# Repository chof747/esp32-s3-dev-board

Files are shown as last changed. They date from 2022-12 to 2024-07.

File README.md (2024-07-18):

# ESP32-S3 Development Board
Minimal development board for an ESP32-S3 MCU.

It contains the following elements:

- ESP32 MCU with all available pins broken out
- Programming header with DTR/RTS mechanism
- Power LED
- Fuse to prevent the worse
- Jumper to disconnect 3v3 from the programmer to be able to test e.g. battery mode while still debugging

## Used Parts:

## Revision History:

- **v1.0**: Initial version (filed for fabrication: 19.11.2022, first successfull assembly: 29.11.2022)
- **v1.1**: Changed serial programmer to UMH3 chip and added boot button

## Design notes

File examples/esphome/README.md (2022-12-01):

# ESP Home example firmware

## Setup instructions

Up until (approx) 21st of December 2022 the ESP32-S3 Devkit Board C1 is not supported by the standard ESPHome version so please do the following:

1. Setup a venv in the esphome samples directory 
2. Activate the environment 
3. Install the development version of esphome

```bash
python3 -m venv esphome-dev
source esphome-dev/bin/activate
esphome-dev/bin/python3 -m pip install --upgrade pip
pip3 install https://github.com/esphome/esphome/archive/dev.zip
```

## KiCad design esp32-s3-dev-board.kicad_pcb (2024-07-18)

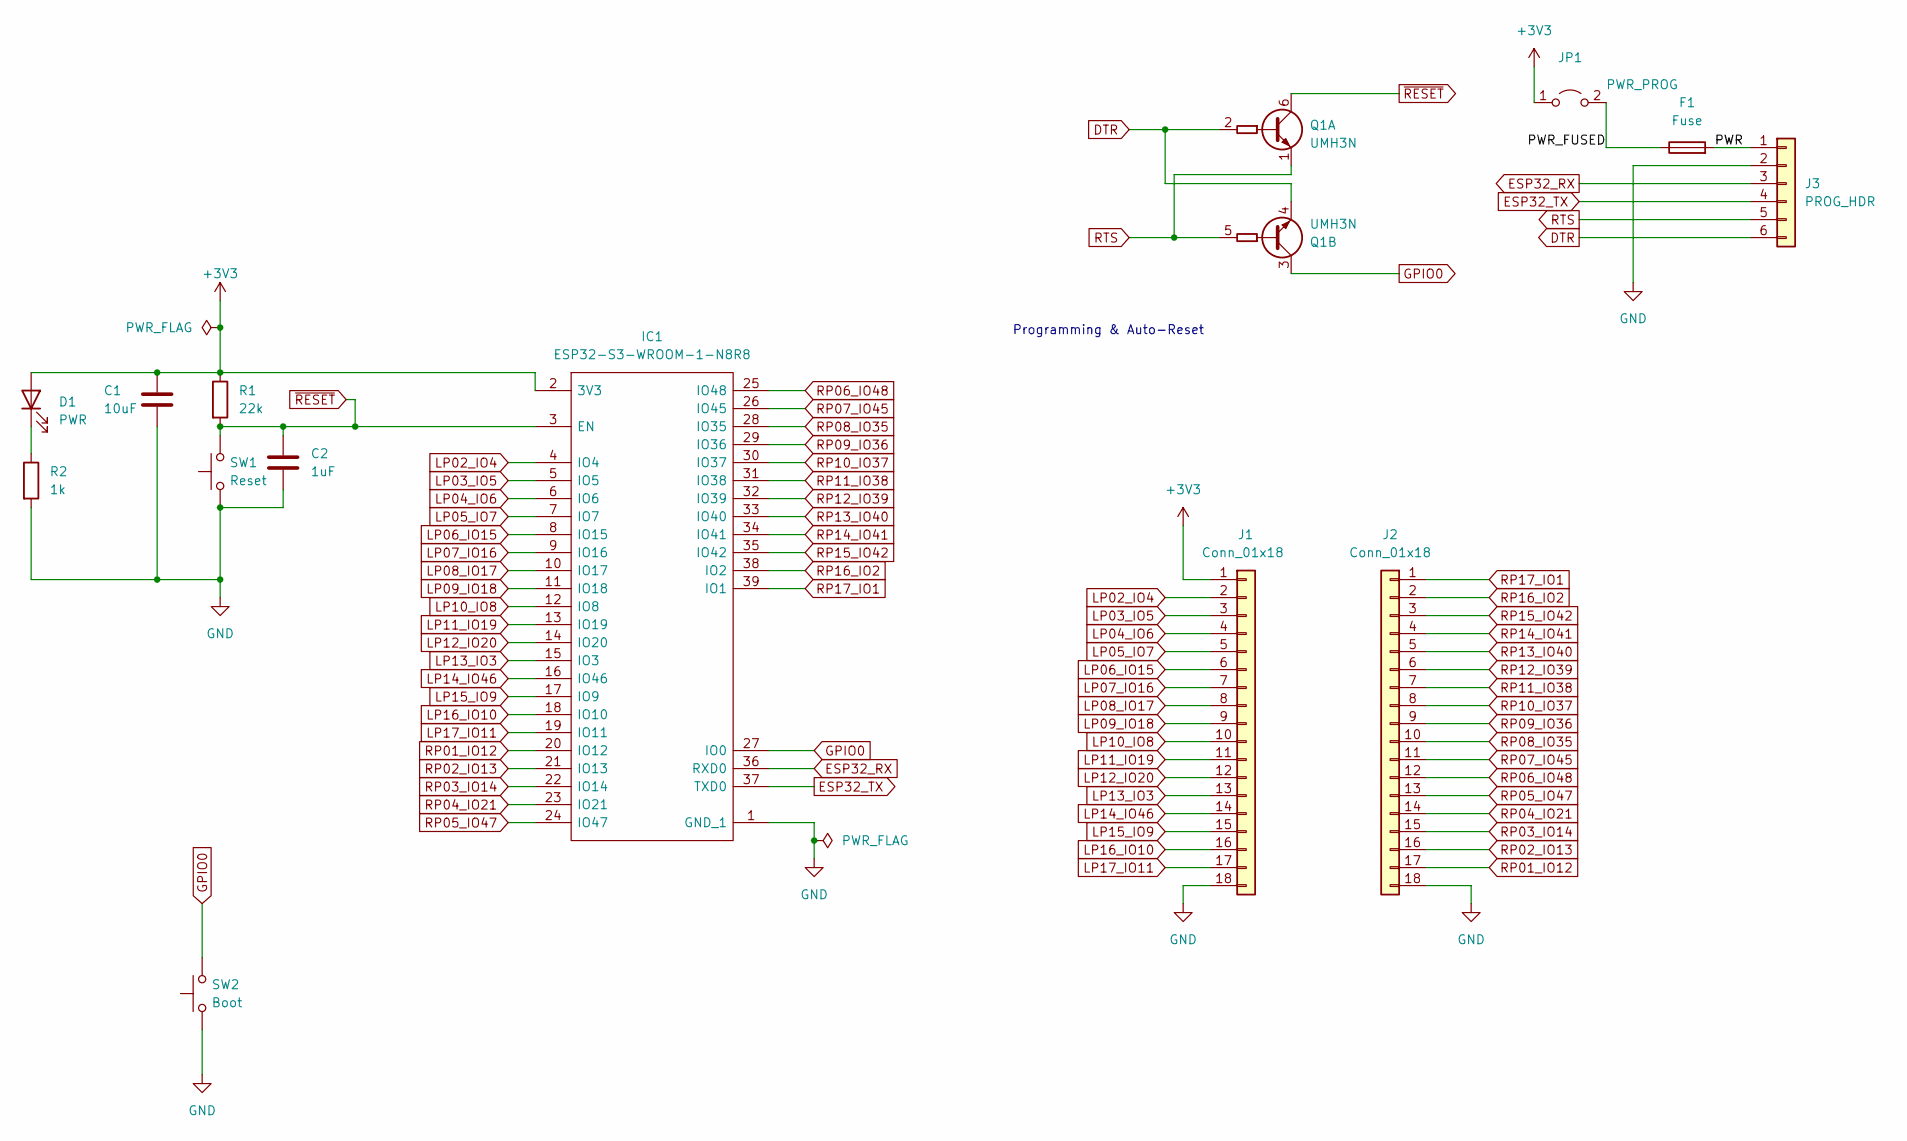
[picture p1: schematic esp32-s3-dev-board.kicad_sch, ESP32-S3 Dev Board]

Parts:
C1: 10uF; C_0603_1608Metric_Pad1.08x0.95mm_HandSolder
C2: 1uF; C_0603_1608Metric_Pad1.08x0.95mm_HandSolder
D1: PWR; LED_0603_1608Metric_Pad1.05x0.95mm_HandSolder
F1: Fuse; Fuse_1206_3216Metric_Pad1.42x1.75mm_HandSolder
IC1: ESP32-S3-WROOM-1-N8R8; ESP32S3WROOM1N8R8; Manufacturer_Part_Number ESP32-S3-WROOM-1-N8R8; Mouser Part Number 356-EP32S3WROOM1N8R8
J1, J2: Conn_01x18; PinHeader_1x18_P2.54mm_Vertical
J3: PROG_HDR; PinHeader_1x06_P2.54mm_Horizontal
JP1: PWR_PROG; PinHeader_1x02_P2.54mm_Vertical
Q1: UMH3N; SOT-363_SC-70-6
R1: 22k; R_0603_1608Metric_Pad0.98x0.95mm_HandSolder
R2: 1k; R_0603_1608Metric_Pad0.98x0.95mm_HandSolder
SW1: Reset; SW_PUSH_6mm
SW2: Boot; SW_PUSH_6mm

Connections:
GPIO0: IC1.27 (IO0), Q1.3 (C2), SW2.2
+3V3: C1.1, D1.2 (A), IC1.2 (3V3), J1.1, JP1.1 (A), R1.1
/PWR: F1.2, J3.1
/PWR_FUSED: F1.1, JP1.2 (B)
DTR: J3.6, Q1.2 (B1), Q1.4 (E2)
ESP32_RX: IC1.36 (RXD0), J3.3
ESP32_TX: IC1.37 (TXD0), J3.4
GND: C1.2, C2.2, IC1.1 (GND_1), J1.18, J2.18, J3.2, R2.2, SW1.1, SW2.1
LP02_IO4: IC1.4 (IO4), J1.2
LP03_IO5: IC1.5 (IO5), J1.3
LP04_IO6: IC1.6 (IO6), J1.4
LP05_IO7: IC1.7 (IO7), J1.5
LP06_IO15: IC1.8 (IO15), J1.6
LP07_IO16: IC1.9 (IO16), J1.7
LP08_IO17: IC1.10 (IO17), J1.8
LP09_IO18: IC1.11 (IO18), J1.9
LP10_IO8: IC1.12 (IO8), J1.10
LP11_IO19: IC1.13 (IO19), J1.11
LP12_IO20: IC1.14 (IO20), J1.12
LP13_IO3: IC1.15 (IO3), J1.13
LP14_IO46: IC1.16 (IO46), J1.14
LP15_IO9: IC1.17 (IO9), J1.15
LP16_IO10: IC1.18 (IO10), J1.16
LP17_IO11: IC1.19 (IO11), J1.17
unnamed: D1.1 (K), R2.1
RP01_IO12: IC1.20 (IO12), J2.17
RP02_IO13: IC1.21 (IO13), J2.16
RP03_IO14: IC1.22 (IO14), J2.15
RP04_IO21: IC1.23 (IO21), J2.14
RP05_IO47: IC1.24 (IO47), J2.13
RP06_IO48: IC1.25 (IO48), J2.12
RP07_IO45: IC1.26 (IO45), J2.11
RP08_IO35: IC1.28 (IO35), J2.10
RP09_IO36: IC1.29 (IO36), J2.9
RP10_IO37: IC1.30 (IO37), J2.8
RP11_IO38: IC1.31 (IO38), J2.7
RP12_IO39: IC1.32 (IO39), J2.6
RP13_IO40: IC1.33 (IO40), J2.5
RP14_IO41: IC1.34 (IO41), J2.4
RP15_IO42: IC1.35 (IO42), J2.3
RP16_IO2: IC1.38 (IO2), J2.2
RP17_IO1: IC1.39 (IO1), J2.1
RTS: J3.5, Q1.1 (E1), Q1.5 (B2)
~RESET: C2.1, IC1.3 (EN), Q1.6 (C1), R1.2, SW1.2

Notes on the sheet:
Programming & Auto-Reset

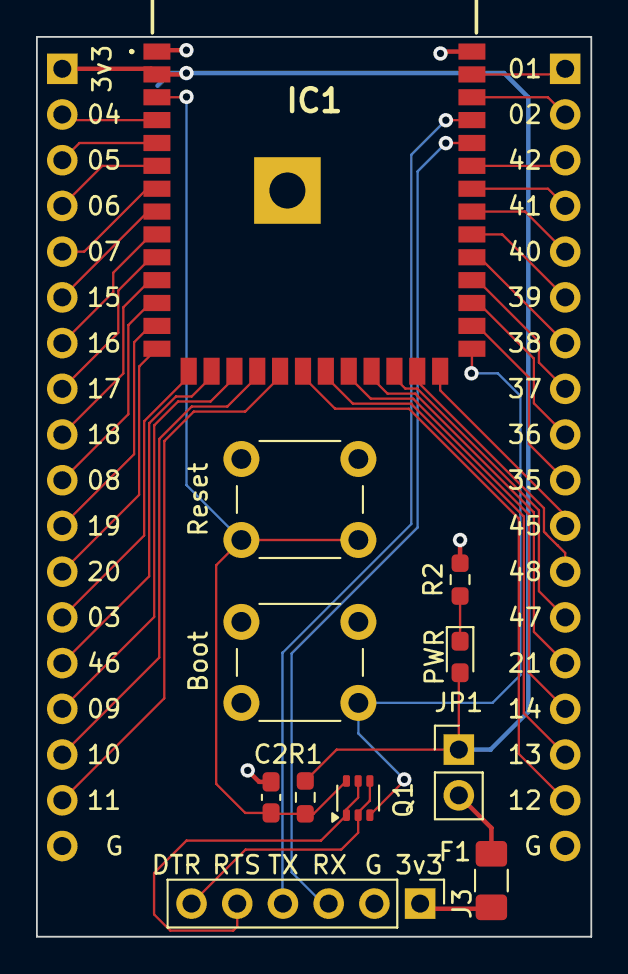
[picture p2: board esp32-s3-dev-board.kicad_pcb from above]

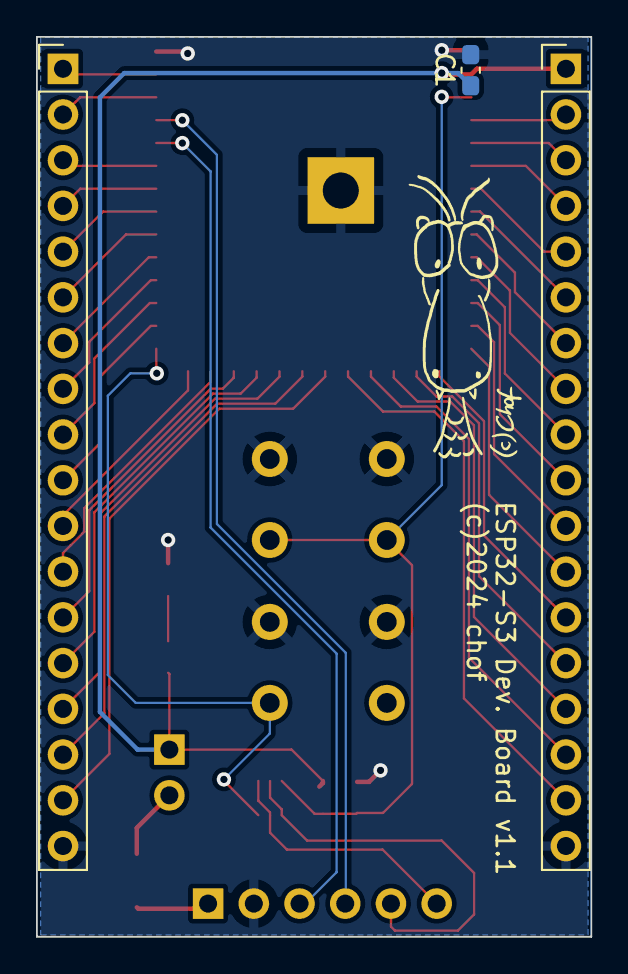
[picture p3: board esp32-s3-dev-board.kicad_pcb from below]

Board: 2 copper layers, 30.8 x 50.0 mm, 14 parts (3 on the bottom side), 44 nets.

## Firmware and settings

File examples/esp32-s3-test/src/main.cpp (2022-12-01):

#include <Arduino.h>
#include <WiFi.h>

#include "config.h"

void setup() {
  // put your setup code here, to run once:
  Serial.begin(115200);
  WiFi.mode(WIFI_STA);
  WiFi.begin(WIFI_SSID, WIFI_PASSWORD);
    Serial.println("\nConnecting");

    while(WiFi.status() != WL_CONNECTED){
        Serial.print(".");
        delay(100);
    }

    Serial.println("\nConnected to the WiFi network");
    Serial.print("Local ESP32 IP: ");
    Serial.println(WiFi.localIP());
    Serial.println(WiFi.gatewayIP());
    Serial.println(WiFi.macAddress());
}

void loop() {
  // put your main code here, to run repeatedly:
  Serial.print("Hello");
  if (WL_CONNECTED == WiFi.status())
  {
        Serial.print(" World on ");
        Serial.println(WiFi.localIP());
  } 
  else
  {
    Serial.println(" nowhere :-(");
  }
  delay(5000);
}

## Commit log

2022-11-20 Initial revision of esp32-dev-board
    [esp32-s3-dev-board.kicad_pcb, esp32-s3-dev-board.kicad_sch]
2022-12-01 Added Example firmwares after first board assembly
    - Added a rudimentary custom build firmware
    - Added a basic esphome configuration
    - Documented first assembly
2023-04-27 Updated template for KiCAD 7
    [esp32-s3-dev-board.kicad_pcb, esp32-s3-dev-board.kicad_sch]
2024-03-15 Changed reset circuit to UMH3N and Upgrade to KiCad 8
    [esp32-s3-dev-board.kicad_pcb, esp32-s3-dev-board.kicad_sch]
2024-07-18 Added version 1.1 with following changes:
    - Changed reset and boot logic to UMH3 chip
    - Added a boot button to allow manual setting into boot mode
    [esp32-s3-dev-board.kicad_pcb, esp32-s3-dev-board.kicad_sch]

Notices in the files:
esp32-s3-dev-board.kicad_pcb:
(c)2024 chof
